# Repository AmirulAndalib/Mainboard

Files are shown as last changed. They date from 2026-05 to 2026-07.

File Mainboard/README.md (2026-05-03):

# Mainboard

## License

Framework Laptop 13 © 2022 by Framework Computer Inc is licensed under CC BY 4.0.
To view a copy of this license, visit http://creativecommons.org/licenses/by/4.0/

# Mechanical

## 2D

2D drawings of the Mainboard with the PCB outline, keepouts, and connector locations.

## OpenSCAD



A basic VESA 75mm mountable 3D printable tray modeled in OpenSCAD, usable as a starting point for more complex cases.

## Printable Case

Case

A fully featured 3D printable case.

# Partial Schematics
Partial schematics are listed for each generation of Framework Laptop 13.  These contain block diagrams, power trees,
and the circuits around each connector.  For full schematics, repair shops can submit a request to our support team
with the serial number of the Mainboard.

Note: Framework Laptop 13 (13th Gen Intel Core) uses the same schematic as (12th Gen Intel Core).

# Framework Laptop Mainboard Pinouts

This is a list of connectors on the Framework Laptop Mainboard and the pinouts for them.
Note that not all signals listed in each pinout are actually connected on any given
version of Mainboard.  These are the overarching definitions of the pinouts with some
considerations for future generations that may or may not utilize the additional signals.

## Webcam Interface

IPEX 20879-030E connector used to interface to the Webcam Module.  Note that the Webcam Module
itself currently only uses a 12 pin connector using pins 19 through 30.  The remaining signals
are not connected.

| Pin | Signal | Type (on Mainboard) | Notes |
|-----|---|---|---|
| 1 | GND | | |
| 2 | CSI_0N | Input | MIPI Lane 0 |
| 3 | CSI_0P | Input | MIPI Lane 0 |
| 4 | GND | | |
| 5 | CSI_1N | Input | MIPI Lane 1 |
| 6 | CSI_1P | Input | MIPI Lane 1 |
| 7 | GND | | |
| 8 | CSI_CLKN | Input | MIPI Clock |
| 9 | CSI_CLKP | Input | MIPI Clock |
| 10  | GND | | |
| 11  | SYNC_CAM | Input/Output | Camera FSIN (Frame Sync) |
| 12  | SCL_CAM  | Input | |
| 13  | SDA_CAM  | Input/Output | |
| 14  | TS_SYNC  | Output | Touchscreen frame sync |
| 15  | TS_RST | Output | Touchscreen reset |
| 16  | TS_INT | Input | Touchscreen interrupt |
| 17  | TS_SDA | Input/Output | Touchscreen data |
| 18  | TS_SCL | Output | Touchscreen data |
| 19  | GND | | |
| 20  | USB_DP | Input/Output | Touchscreen or camera USB 2.0 |
| 21  | USB_DM | Input/Output | Touchscreen or camera USB 2.0 |
| 22  | 3V3 | | |
| 23  | CAM_SW | Input | 3v3 |
| 24  | MIC_CLK  | Output | 1v8 |
| 25  | MIC_DAT  | Input | 1v8 |
| 26  | MIC_SW | Input | 3v3 |
| 27  | INT_ALS  | Input | 3v3 |
| 28  | SCL_ALS  | Output | 3v3 |
| 29  | SDA_ALS  | Input/Output | 3v3 |
| 30  | GND | | |

## Display Interface

IPEX 20879-040E connector used to interface to an eDP display.  Note that there are signals
defined for both USB 2.0 and I2C touchscreens.  There is a PWM interface to control backlight
brightness, but the display currently used on the Framework Laptop converts that to a DC LED
control.  Note that pin 1 is on the left when looking at the receptacle on the Mainboard.

| Pin | Signal | Description |
|-----|---|---|
| 1 | BL_POWER | 12-17V backlight power |
| 2 | BL_POWER | |
| 3 | BL_POWER | |
| 4 | NC | |
| 5 | GND | |
| 6 | AUXP | |
| 7 | AUXN | |
| 8 | GND | |
| 9 | EDP_TXP_0 | |
| 10  | EDP_TXN_0 | |
| 11  | GND | |
| 12  | EDP_TXP_1 | |
| 13  | EDP_TXN_1 | |
| 14  | GND | |
| 15  | EDP_TXP_2 | |
| 16  | EDP_TXN_2 | |
| 17  | GND | |
| 18  | EDP_TXP_3 | |
| 19  | EDP_TXN_3 | |
| 20  | GND | |
| 21  | EDP_HPD | hotplug |
| 22  | BLK_PWM_LCD | Backlight PWM |
| 23  | BLK_OFF_N | Backlight Enable |
| 24  | NC | |
| 25  | NC | |
| 26  | 3V_EDP | 3VS |
| 27  | 3V_EDP | |
| 28  | 3V_EDP | |
| 29  | 3V_TS | 3VS for touchscreen |
| 30  | 3V_TS | |
| 31  | USB_DP | USB |
| 32  | USB_DN | |
| 33  | TS_EN | |
| 34  | TS_RST | |
| 35  | TS_INT_N | |
| 36  | TS_SDA | |
| 37  | TS_SCL | |
| 38  | NC | |
| 39  | GND | |
| 40  | GND | |

## Audio Board Interface

Hefeng AFC42-S15FMA-R3 ZIF connector that goes to the board that has the 3.5mm
audio jack as well as the hall effect lid sensor.  Note that there are likely
other 15 pin 0.5mm pitch ZIF connectors that will work with the FFC we use, but
these would be untested.

| Pin | Signal |
|-----|---|
| 1 | A_GND |
| 2 | HPOUT_L |
| 3 | HPOUT_R |
| 4 | SLEEVE |
| 5 | SLEEVE |
| 6 | SLEEVE |
| 7 | RING |
| 8 | RING |
| 9 | RING |
| 10  | A_GND |
| 11  | JACK_PLUG |
| 12  | 3V3_HALL  |
| 13  | LID_OPEN  |
| 14  | BOARD_ID  |
| 15  | GND |

## Speaker Interface

Hefeng AWA02-S04FIA-HF connector for the Speakers.  Note that there are many other footprint
compatible 4-pin connectors that are likely compatible. This kind of connector is also known
as "JST SH", and has a 1.0 mm pitch. The same connector is used for the Fan.

| Pin | Signal |
|-----|---|
| 1 | SPK_RP |
| 2 | SPK_RN |
| 3 | SPK_LP |
| 4 | SPK_LN |

## Battery Interface

ACES 50458-01001-001 connector for the Battery.

| Pin | Signal | Notes  |
|-----|---|---|
| 1 | BAT+ | 24 AWG |
| 2 | BAT+ | 24 AWG |
| 3 | BAT+ | 24 AWG |
| 4 | CLK_SMB  | SMBus  |
| 5 | DAT_SMB  | SMBus  |
| 6 | BATT_PRS | |
| 7 | SYS_PRES | |
| 8 | GND | 24 AWG |
| 9 | GND | 24 AWG |
| 10  | GND | 24 AWG |

## Input Cover Interface

Amphenol 10156000-051100LF connector for the Input Cover.  This includes signals
for the Touchpad, Keyboard, and Fingerprint Reader. The mating connector for it
is 10156001-051100LF.

Caution: this pinout is Framework schematic-specific, using a symbol with odd-even numbering.
It doesn't translate directly to the Amphenol connector footprint numbering - which is
counterclockwise. Amphenol connector numbering is shown in the "Conn" column.

| Pin | Conn | Signal | Notes |
|-----|---|---|---|
| 1 | 1 | GND | |
| 2 | 50 | KSI0 | Keyboard scanning input 0 |
| 3 | 2 | KSI1 | Keyboard scanning input 1 |
| 4 | 49 | KSI2 | Keyboard scanning input 2 |
| 5 | 3 | KSI3 | Keyboard scanning input 3 |
| 6 | 48 | KSI4 | Keyboard scanning input 4 |
| 7 | 4 | KSI5 | Keyboard scanning input 5 |
| 8 | 47 | KSI6 | Keyboard scanning input 6 |
| 9 | 5 | KSI7 | Keyboard scanning input 7 |
| 10  | 46 | KSO0 | Keyboard scanning output 0 |
| 11  | 6 | KSO1 | Keyboard scanning output 1 |
| 12  | 45 | KSO2 | Keyboard scanning output 2 |
| 13  | 7 | KSO3 | Keyboard scanning output 3 |
| 14  | 44 | KSO4 | Keyboard scanning output 4 |
| 15  | 8 | KSO5 | Keyboard scanning output 5 |
| 16  | 43 | KSO6 | Keyboard scanning output 6 |
| 17  | 9 | KSO7 | Keyboard scanning output 7 |
| 18  | 42 | KSO8 | Keyboard scanning output 8 |
| 19  | 10 | KSO9 | Keyboard scanning output 9 |
| 20  | 41 | KSO10 | Keyboard scanning output 10  |
| 21  | 11 | KSO11 | Keyboard scanning output 11  |
| 22  | 40 | KSO12 | Keyboard scanning output 12  |
| 23  | 12 | KSO13 | Keyboard scanning output 13  |
| 24  | 39 | KSO14 | Keyboard scanning output 14  |
| 25  | 13 | KSO15 | Keyboard scanning output 15  |
| 26  | 38 | GND | |
| 27  | 14 | CAPS_P | +5VS through 1.33k resistor  |
| 28  | 37 | CAPS_N | Low-side control by the EC |
| 29  | 15 | GND | |
| 30  | 36 | KBL_P | High-side 5V PWM by the EC |
| 31  | 16 | GND | |
| 32  | 35 | KBL_P | Same as 30 - see [1] |
| 33  | 17 | GND | |
| 34  | 34 | TP_SCL | Touchpad I2C SCL |
| 35  | 18 | TP_INT | Touchpad interrupt GPIO |
| 36  | 33 | TP_SDA | Touchpad I2C SDA |
| 37  | 19 | TP_BOARD_ID | |
| 38  | 32 | 5VS | 5V, touchpad - see [2] |
| 39  | 20 | 5VALW | 5V, fingerprint, see [3] |
| 40  | 31 | USB_DM | Fingerprint sensor USB |
| 41  | 21 | GND | |
| 42  | 30 | USB_DP | Fingerprint sensor USB |
| 43  | 22 | FPR_CTRL | See [4] |
| 44  | 29 | SWITCH | Power button pin |
| 45  | 23 | FPR_LED_R | Low-side control by the EC |
| 46  | 28 | FPR_LED_W | Low-side control by the EC |
| 47  | 24 | FPR_LED_G | Low-side control by the EC |
| 48  | 27 | FPR_LED_COM | 5V, fingerprint LED, see [3] |
| 49  | 25 | GND | |
| 50  | 26 | NC | |

- [1] The connector has two KBL_P pins - in order to increase current capacity. They're created from +5VS rail.
- [2] Connected to the +5VS (switched) rail through a 0 ohm resistor
- [3] Connected to the +5VALW (always-on) rail through a 0 ohm resistor
- [4] FPR_CTRL is used to filter out power button presses while the fingerprint sensor is scanning

## Fan Interface

Hefeng AWA02-S04FIA-HF connector for the Fan.  Note that there are many other footprint
compatible 4-pin connectors that are likely compatible. This kind of connector is also known
as "JST SH", and has a 1.0 mm pitch. The same connector is used for the Speakers.

| Pin | Signal |
|-----|---|
| 1 | 5V |
| 2 | FAN_SPEED |
| 3 | FAN_PWM |
| 4 | GND |

## RTC Battery Interface

NOTE: The mainboard will charge this battery, so a rechargable ML1220 battery MUST be used.
For example, CR2032 MUST NOT be used, it cannot be charged and will likely be damaged.

RTC battery is used for storing persistent but resettable information.
This includes the time and DRAM training. Disconnection will result in deletion of that information.
If no battery is connected, DRAM training needs to happen on every boot, slowing down the boot process significantly.

### Onboard RTC Battery

Framework 13 Intel Core 11th through 13th Generation use an onboard coin cell battery as RTC.

We use the Lotes LOTES_AAA-BAT-046-K01 connector.

### RTC Battery Cable Connector

On AMD Platforms and starting with Framework 13 Intel Core Ultra Series 1, no RTC battery is included anymore.
Settings are kept alive by the normal system battery. The only case where an
RTC battery is recommended, is when the system is used in standalone mode (without a battery).

Cvilux CVILU_CI4402M1HRC-NH connector for the RTC Battery.

| Pin | Signal | Location |
|-----|---|---|
| 1 | +RTCBATT  | Left |
| 2 | GND | Right |

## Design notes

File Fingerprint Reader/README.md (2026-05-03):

## Fingerprint Reader

## License

Framework Laptop 13 © 2022 by Framework Computer Inc is licensed under CC BY 4.0.
To view a copy of this license, visit http://creativecommons.org/licenses/by/4.0/

## Pinout

The Fingerprint Reader resides on the Input Cover and connects through the Touchpad.
All of its signals are directly passed to the Input Cover Interface described in the
Mainboard documentation. The connector used is Kyocera 046809610110846+.

| Pin | Signal | Notes |
|-----|---|---|
| 1 | VBUS | 5V |
| 2 | USB_DP | USB data |
| 3 | USB_DM | USB data |
| 4 | GND | |
| 5 | FPR_CTRL | Output (mask switch events)  |
| 6 | SWITCH | Open collector output |
| 7 | FPR_LED_W | |
| 8 | FPR_LED_G | |
| 9 | FPR_LED_R | |
| 10  | FPR_LED_COM | 5V |

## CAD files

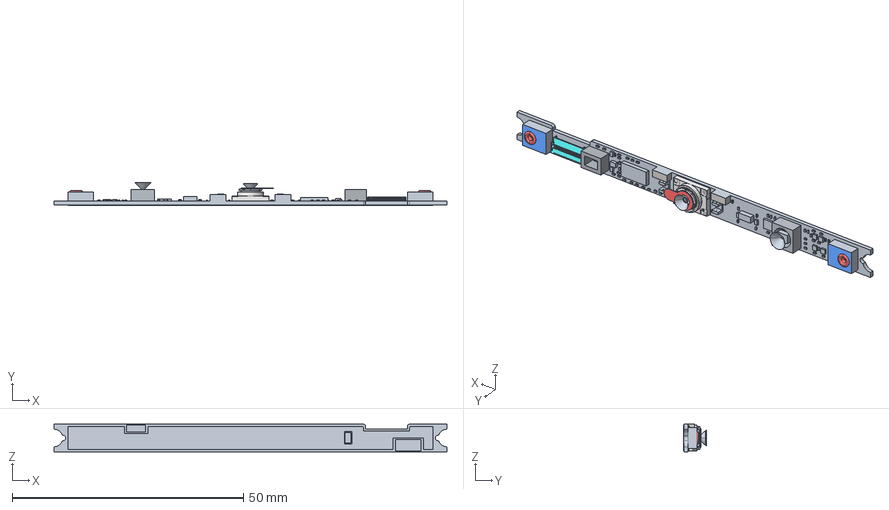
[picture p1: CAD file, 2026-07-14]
Webcam/FW_13_camera_module.stp
85.0 x 4.93 x 6.00 mm

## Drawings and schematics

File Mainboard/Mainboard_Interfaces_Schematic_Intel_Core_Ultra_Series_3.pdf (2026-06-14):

# Block Diagram

## CAMM2

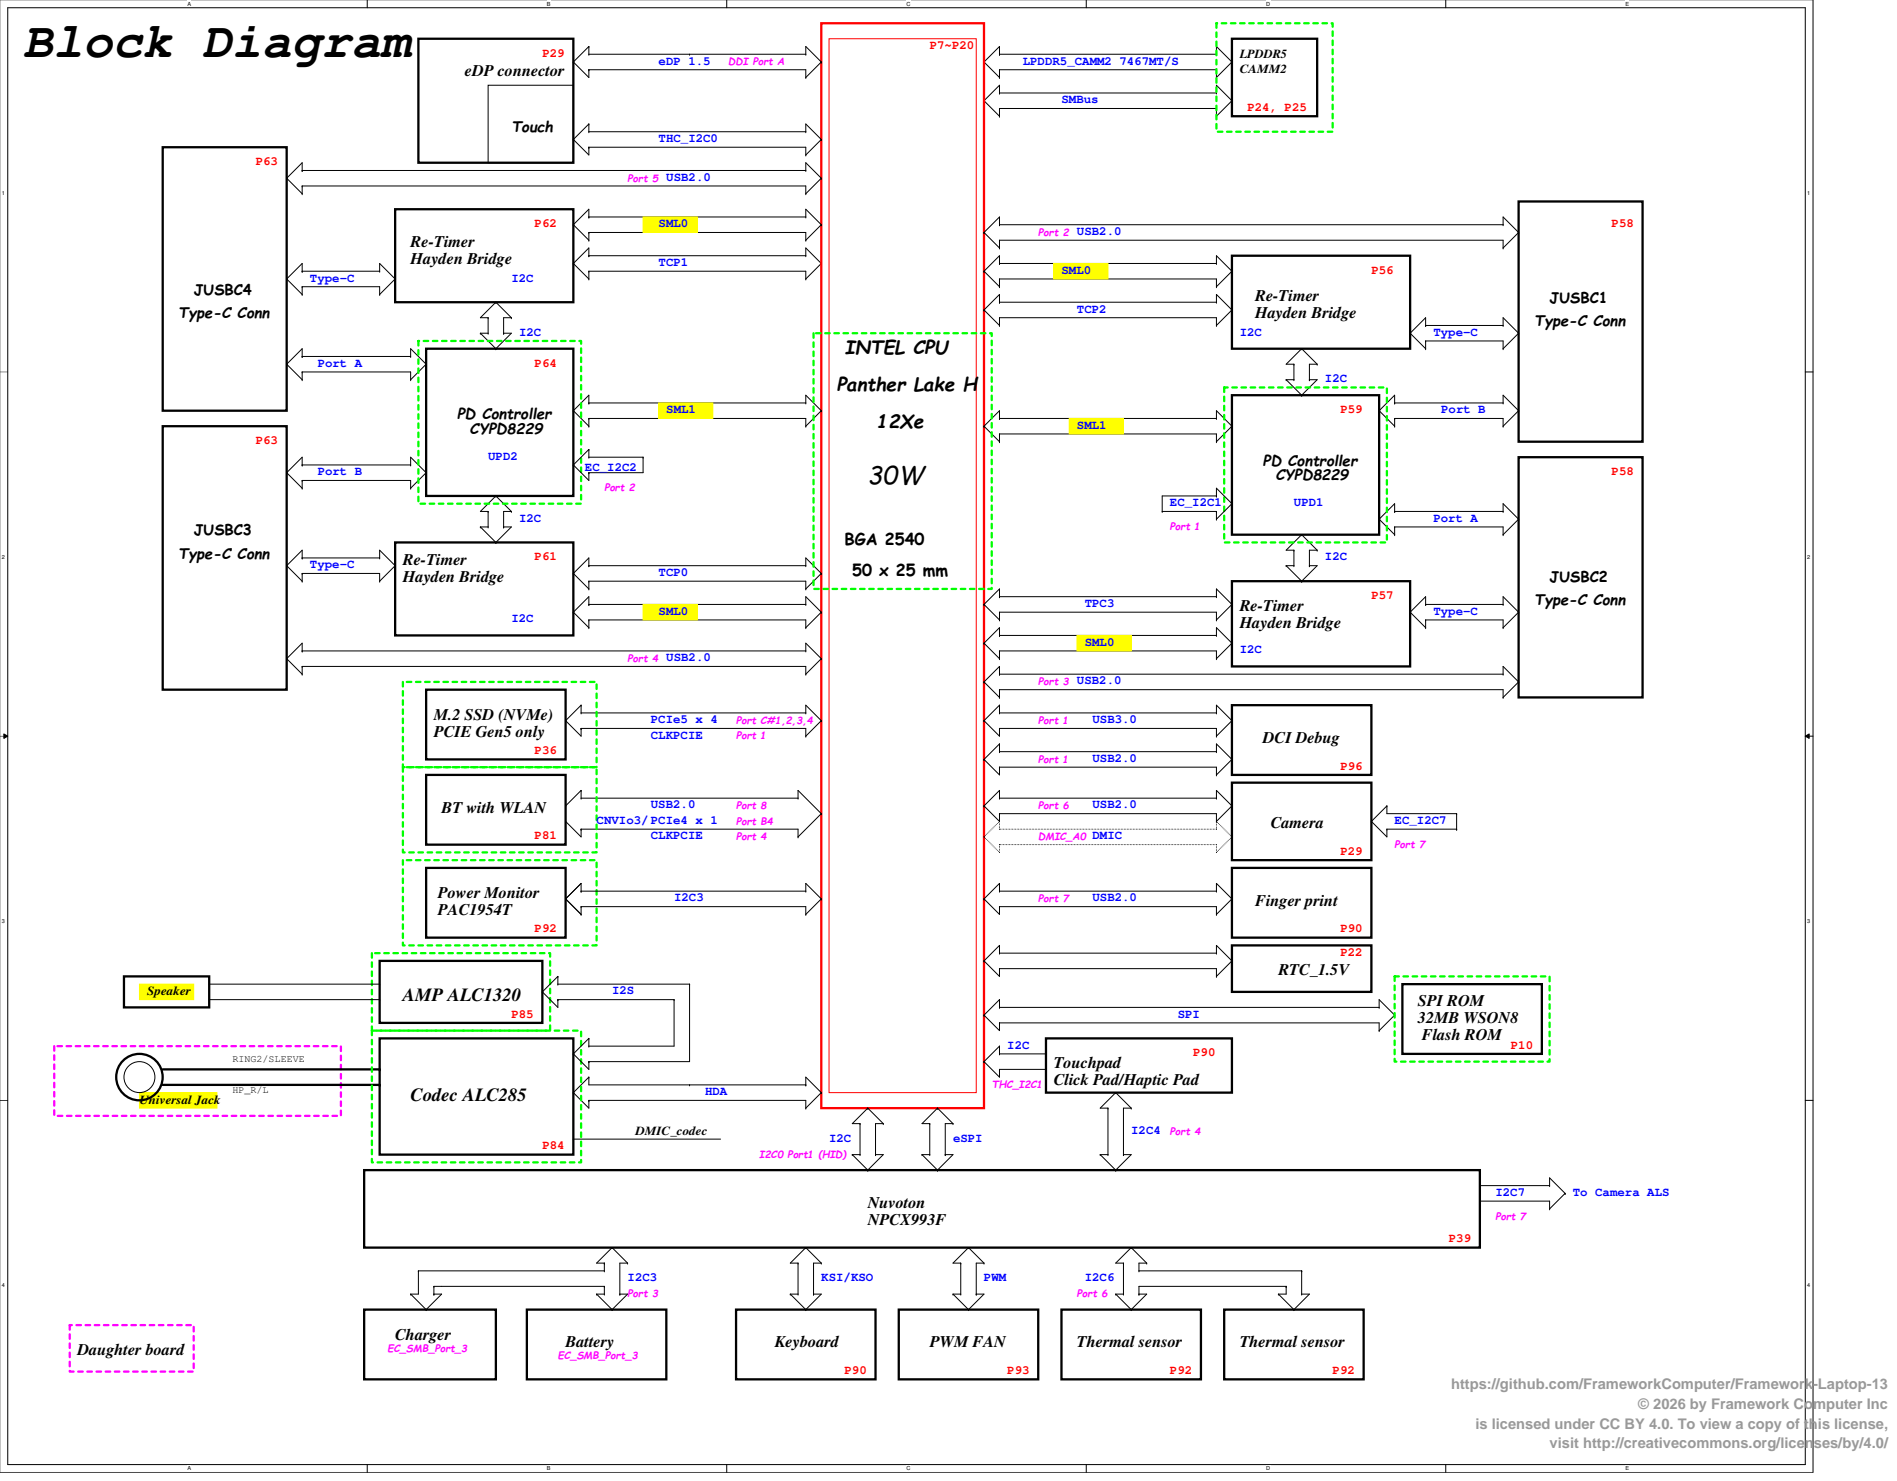
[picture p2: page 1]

Touchpad
Click Pad/Haptic Pad

https://github.com/FrameworkComputer/Framework-Laptop-13

© 2026 by Framework Computer Inc

is licensed under CC BY 4.0. To view a copy of this license,

visit http://creativecommons.org/licenses/by/4.0/

+18.2VB

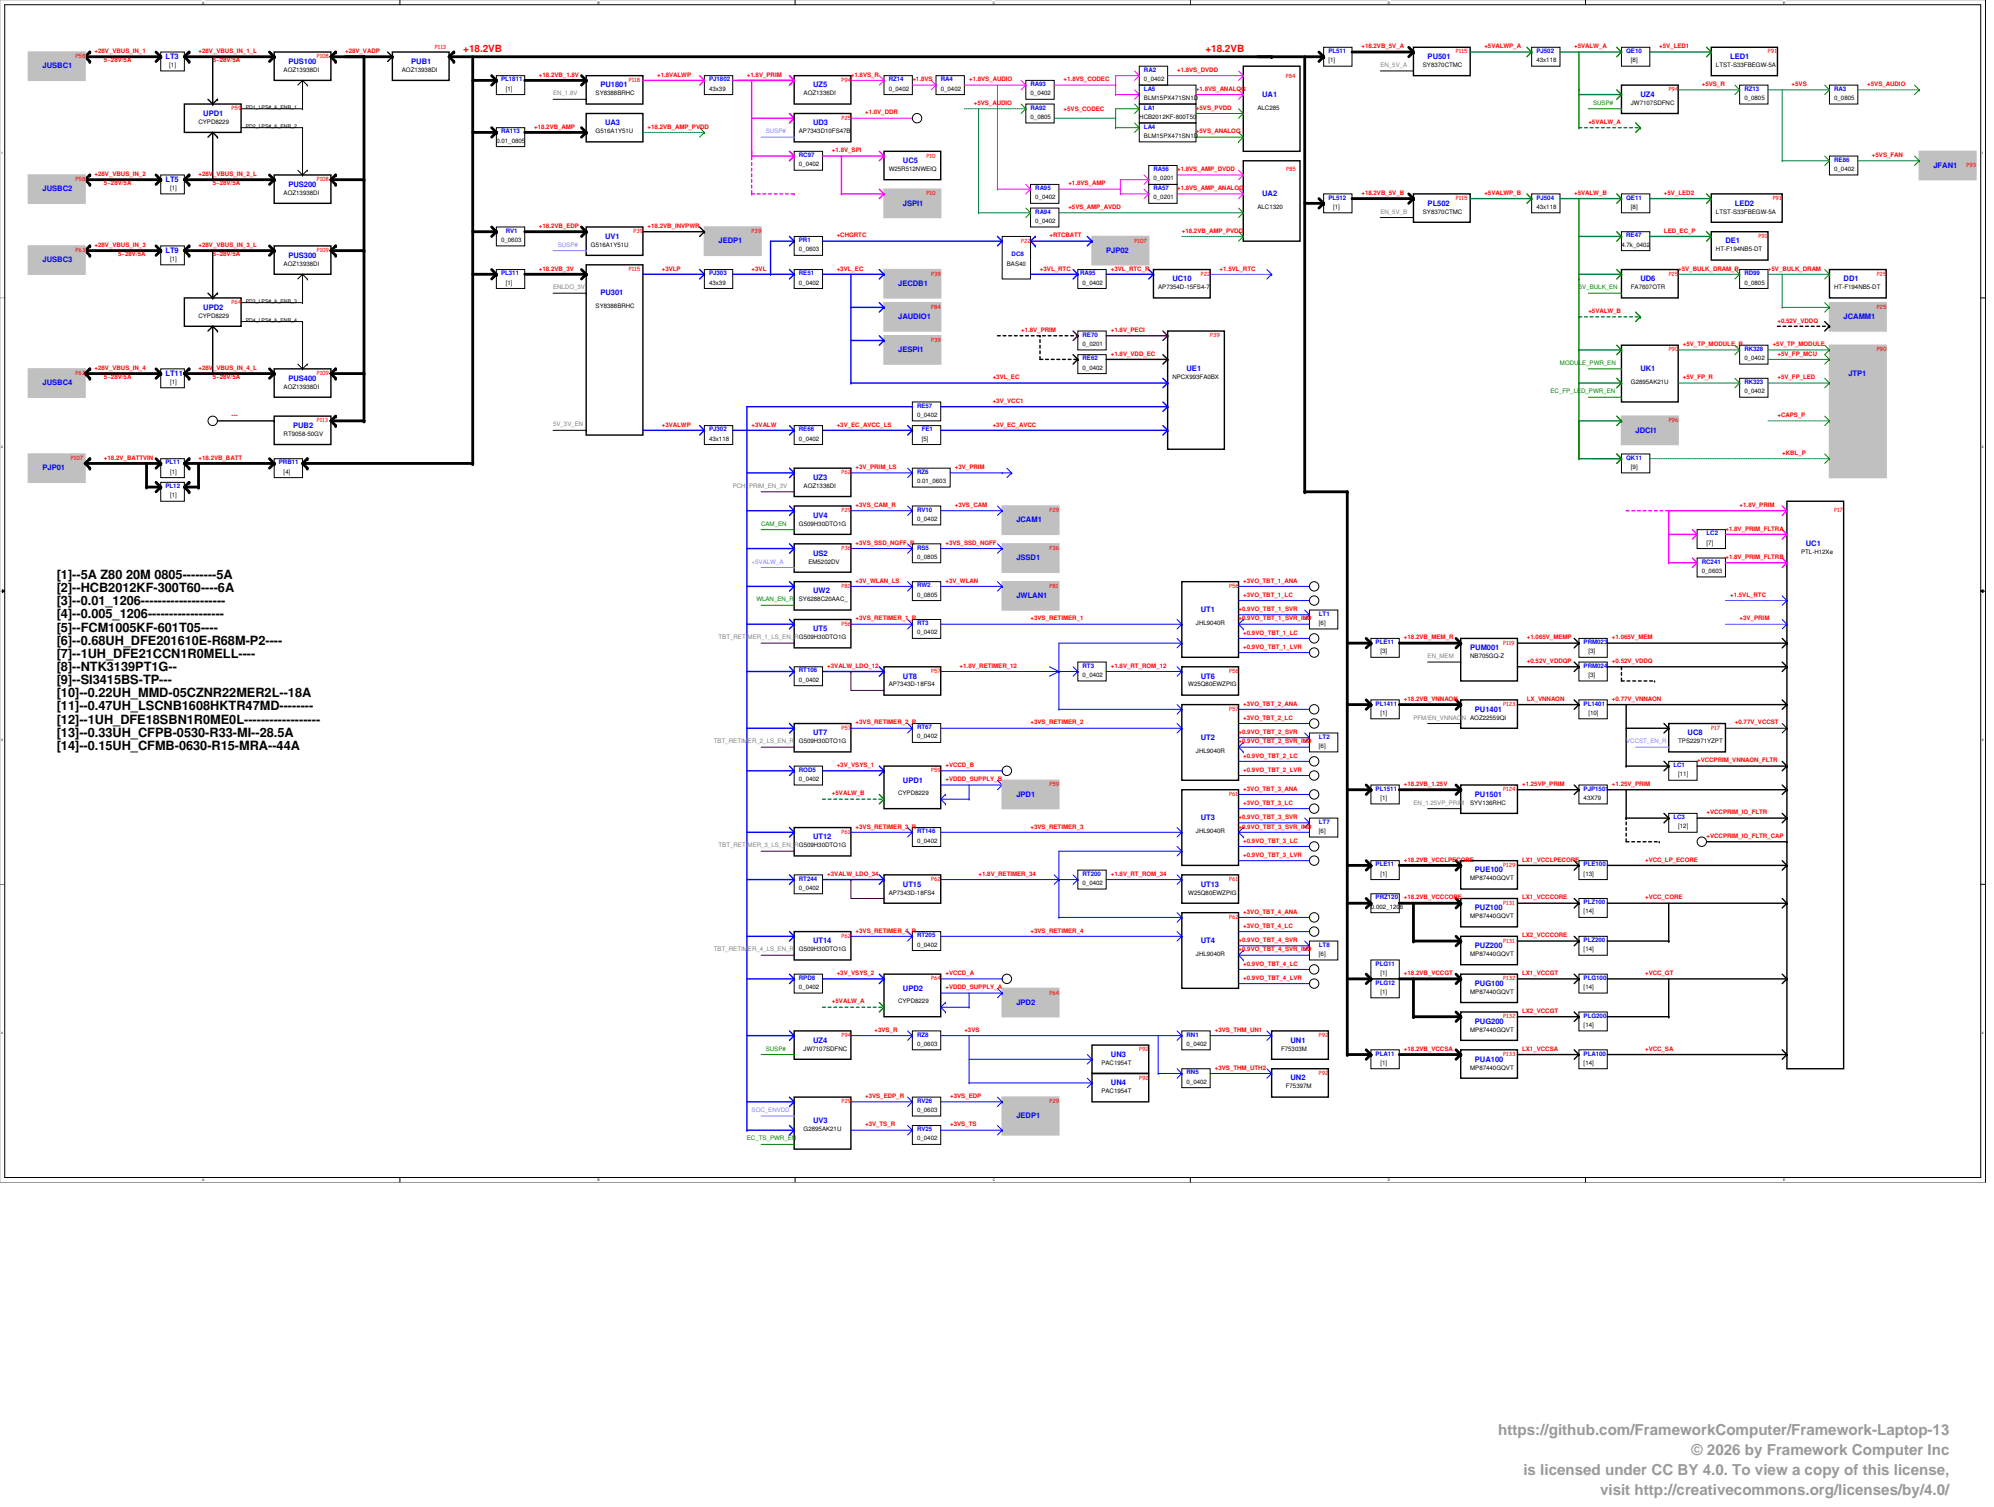
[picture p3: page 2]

# eDP

# eDP Logic and Touch Screen power

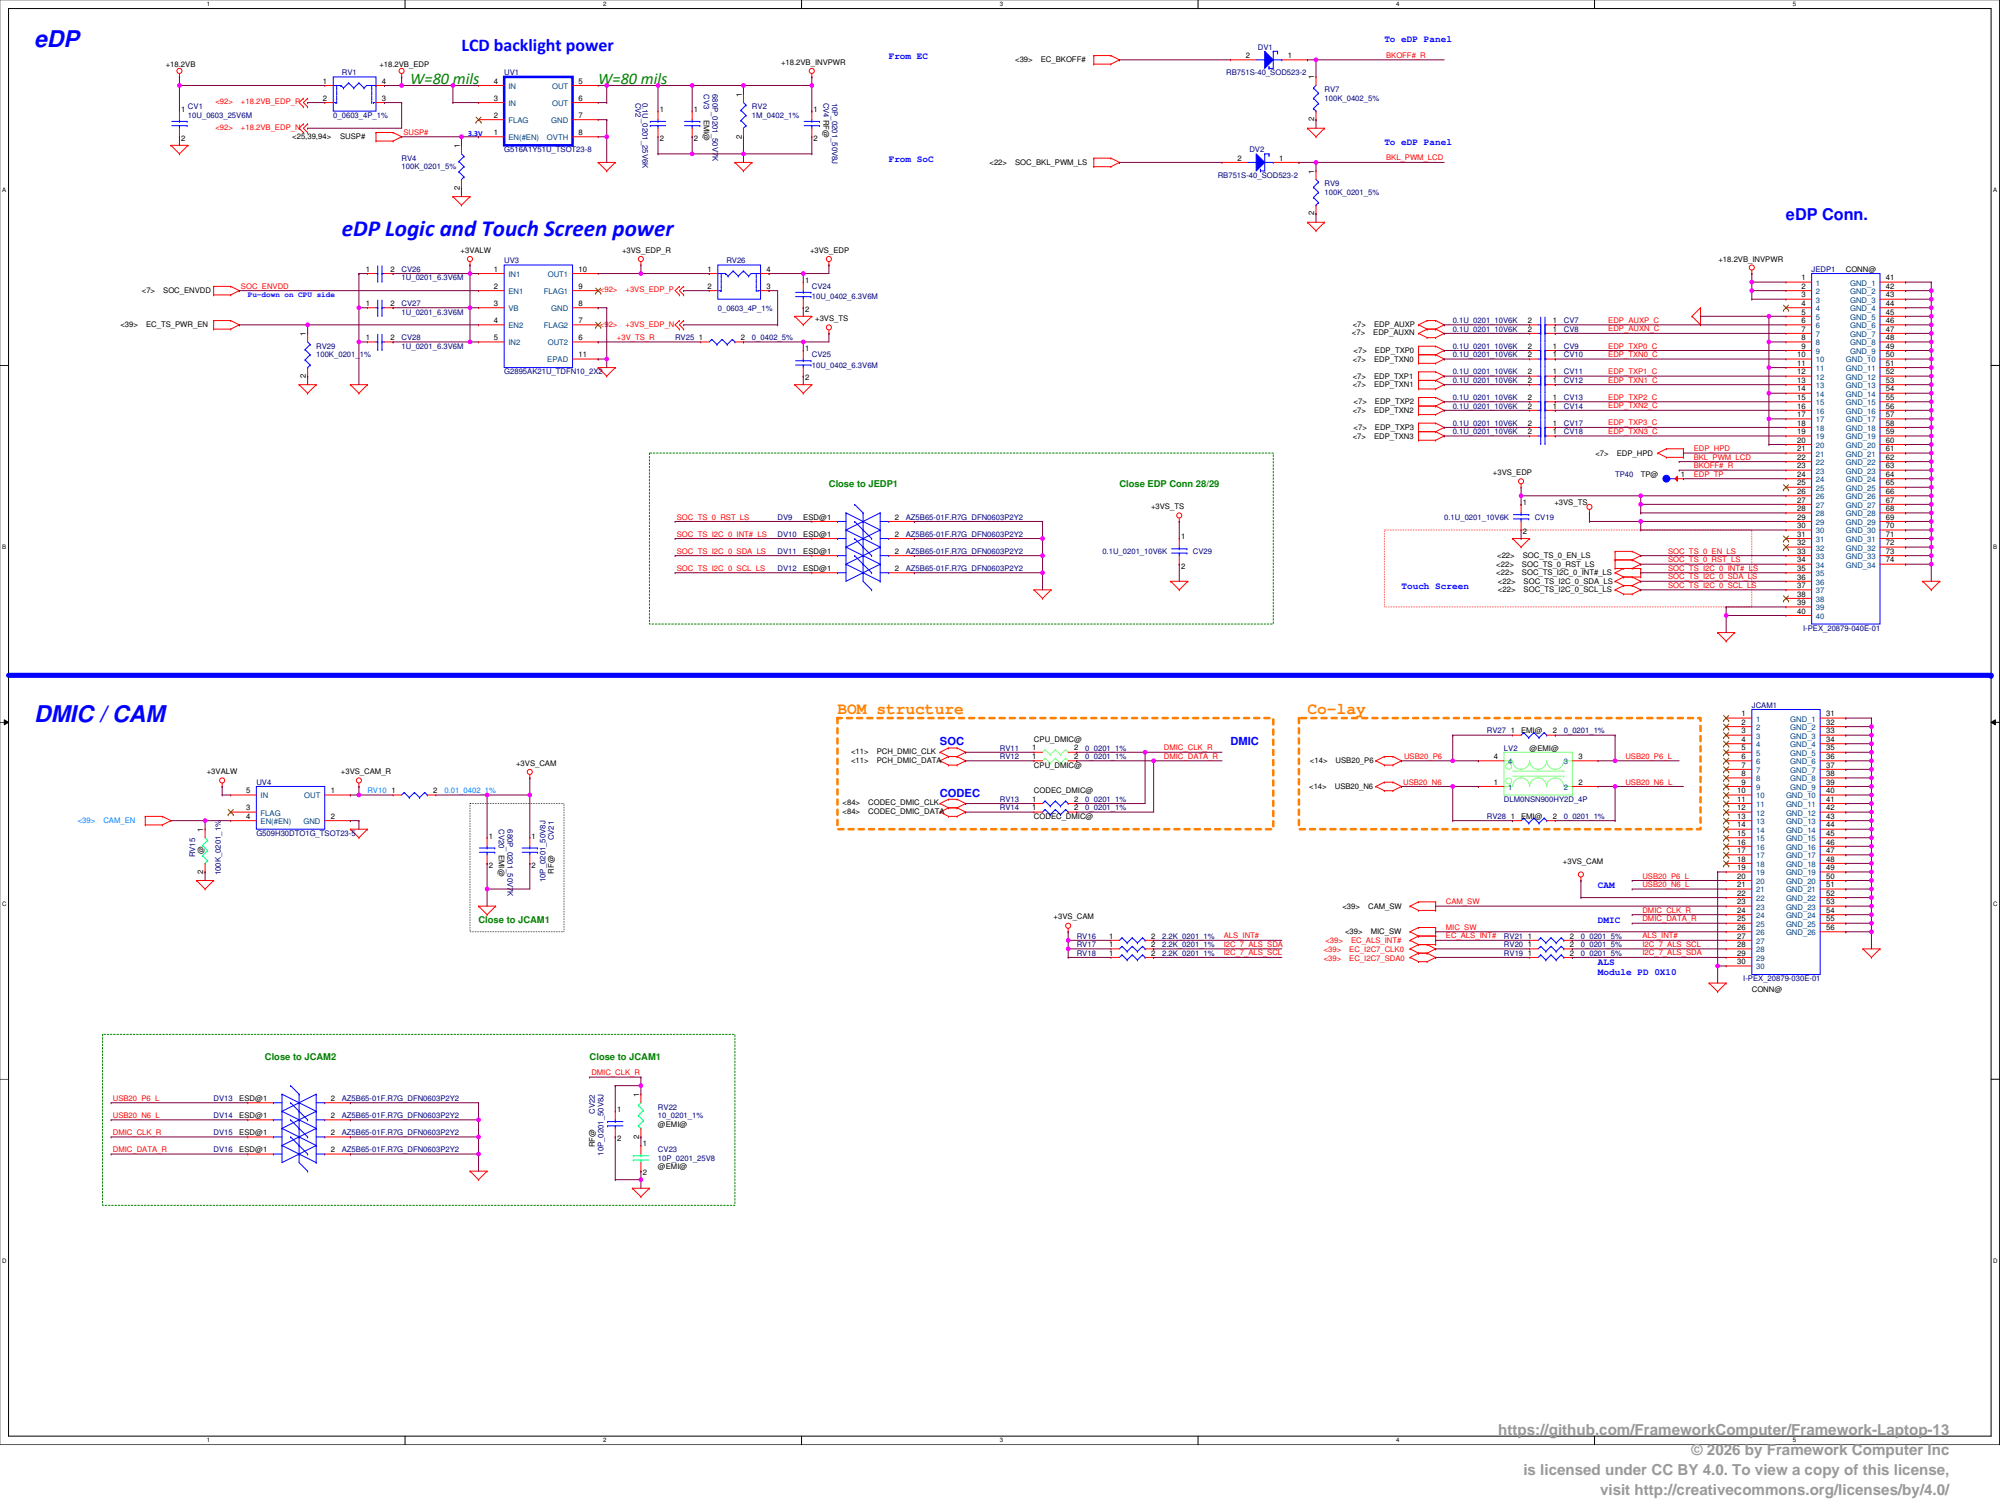
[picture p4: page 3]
From SoC; From EC; DMIC / CAM; CAM; ALS Module PD 0X10; DMIC; W=80 mils; SOC; CODEC; BOM structure; Close to JEDP1; eDP Conn.; Touch Screen; Co-lay; Close to JCAM1; Close to JCAM2; <22> SOC_BKL_PWM_LS; <39> MIC_SW; <39> CAM_SW; <39> CAM_EN; SUSP#; <39> EC_BKOFF#; <7> SOC_ENVDD; <39> EC_TS_PWR_EN; <39> EC_ALS_INT#; <11> PCH_DMIC_CLK <11> PCH_DMIC_DATA; <84> CODEC_DMIC_CLK <84> CODEC_DMIC_DATA; <14> USB20_P6; <14> USB20_N6; <7> EDP_AUXP <7> EDP_AUXN; <7> EDP_TXP0 <7> EDP_TXN0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

LCD backlight power

To eDP Panel

SOC_ENVDD
Pu-down on CPU side

Close EDP Conn 28/29

# NGFF SSD (KEY M)

# PCIE Gen5

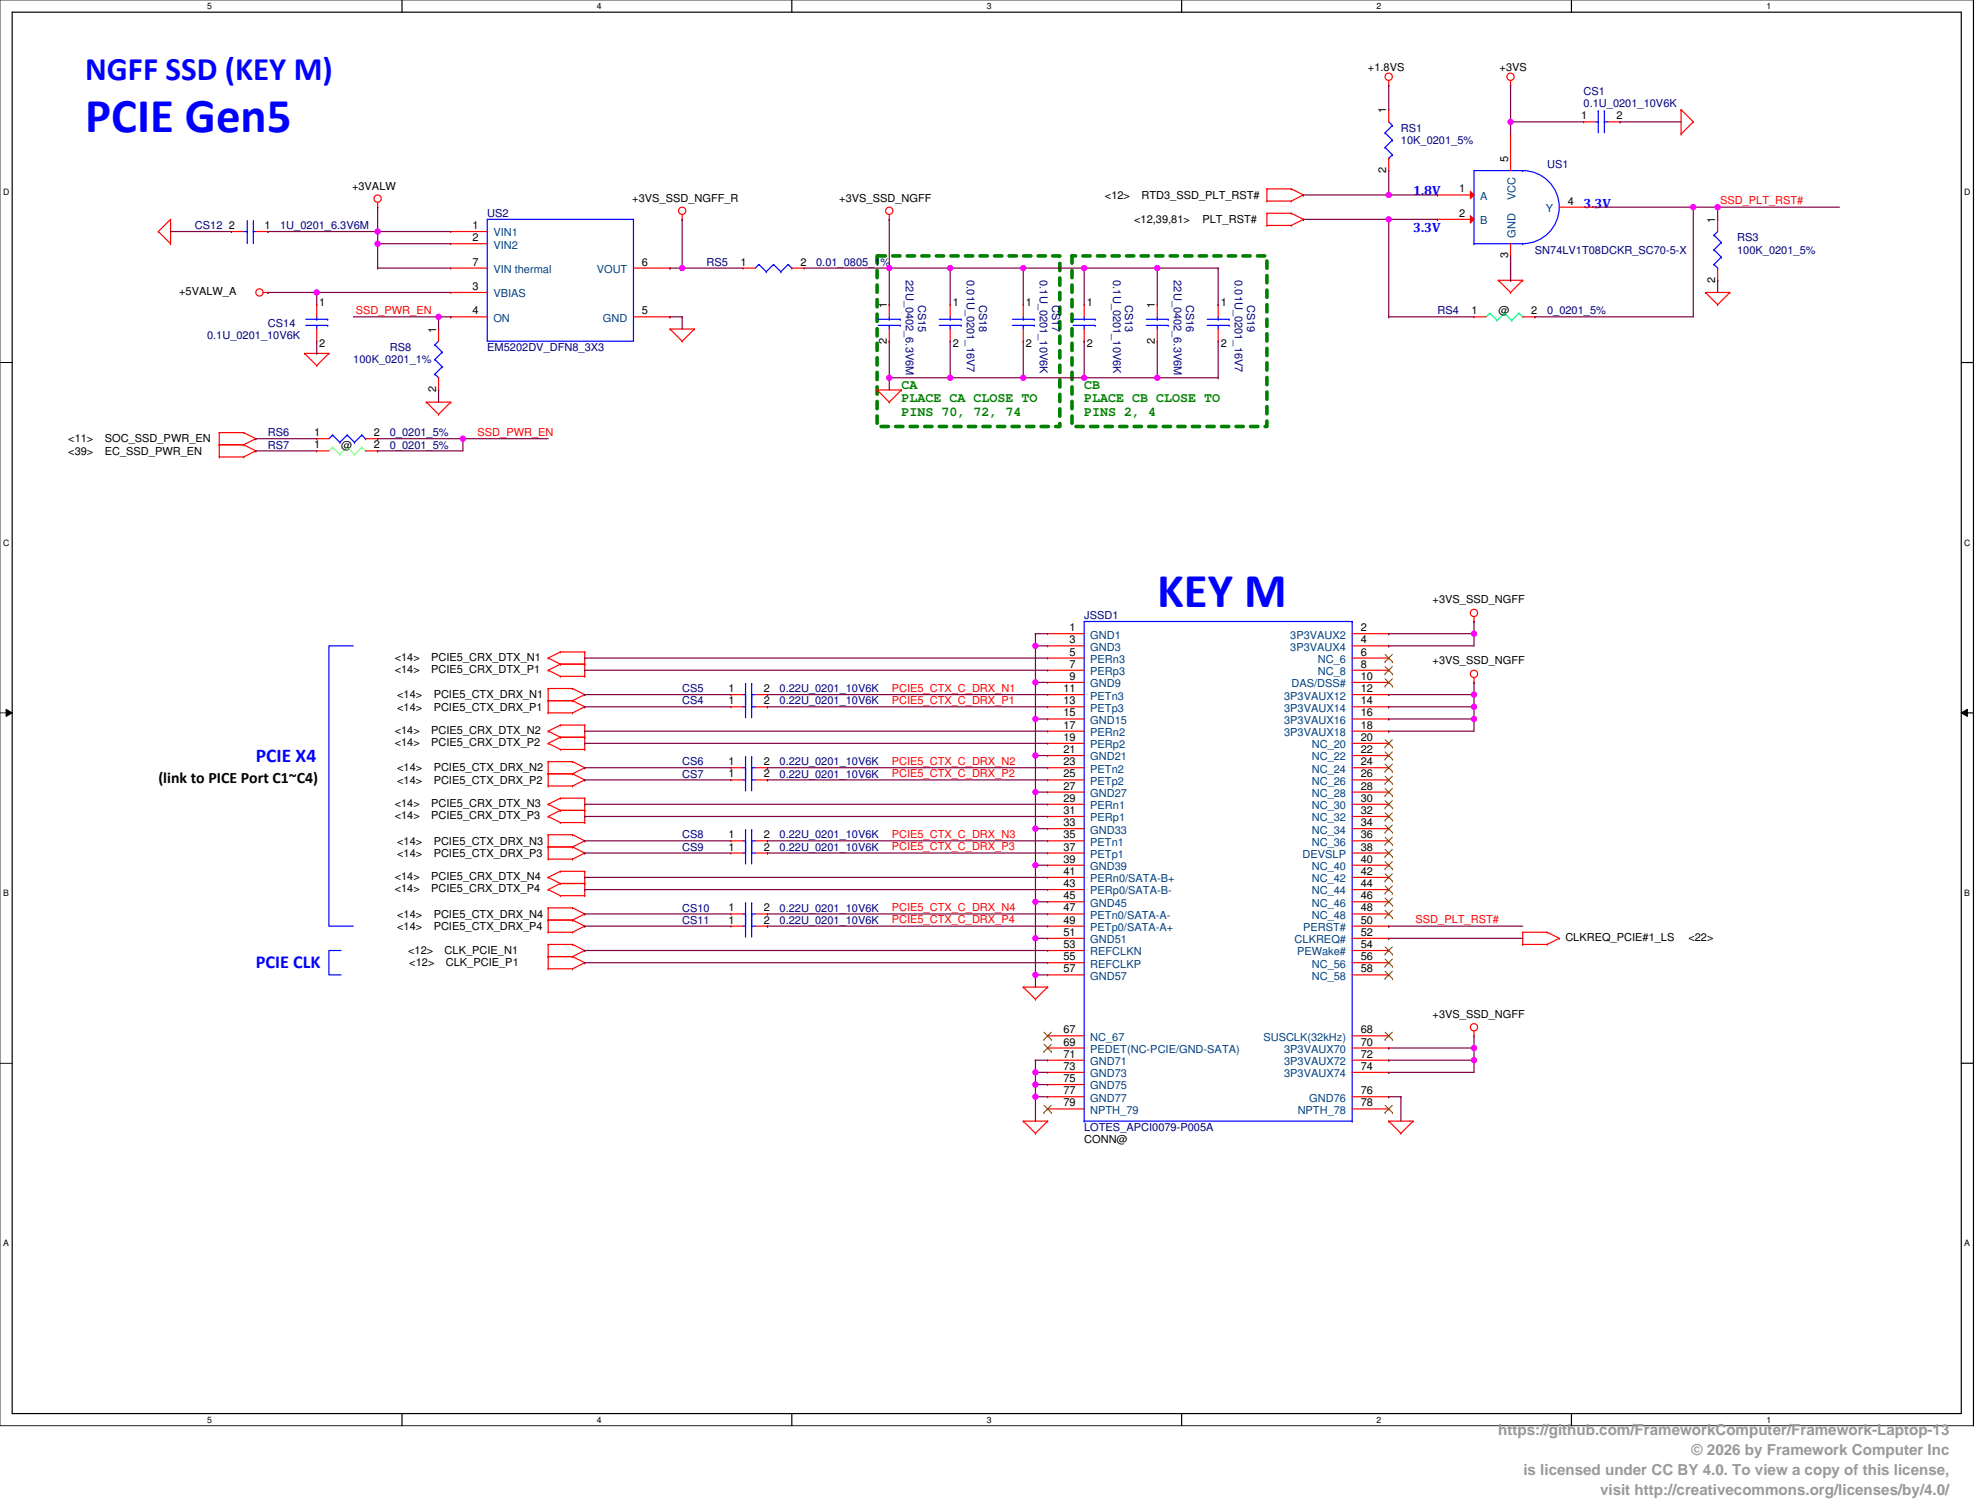
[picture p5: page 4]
PCIE X4; KEY M; PCIE CLK; CLKREQ_PCIE#1_LS; <12> CLK_PCIE_P1; <12> CLK_PCIE_N1; <12> RTD3_SSD_PLT_RST#; <12,39,81> PLT_RST#; <14> PCIE5_CRX_DTX_N3 <14> PCIE5_CRX_DTX_P3; <14> PCIE5_CTX_DRX_N3 <14> PCIE5_CTX_DRX_P3; <14> PCIE5_CRX_DTX_N2 <14> PCIE5_CRX_DTX_P2; <14> PCIE5_CTX_DRX_N2 <14> PCIE5_CTX_DRX_P2; <14> PCIE5_CRX_DTX_N4 <14> PCIE5_CRX_DTX_P4; <14> PCIE5_CTX_DRX_N4 <14> PCIE5_CTX_DRX_P4; <14> PCIE5_CRX_DTX_N1 <14> PCIE5_CRX_DTX_P1; <14> PCIE5_CTX_DRX_N1 <14> PCIE5_CTX_DRX_P1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

PLACE CA CLOSE TO
PINS 70, 72, 74

PLACE CB CLOSE TO
PINS 2, 4

(link to PICE Port C1~C4)

# Imax : 2.0 A

# Main Func = NGFF WLAN / BT (Key E)

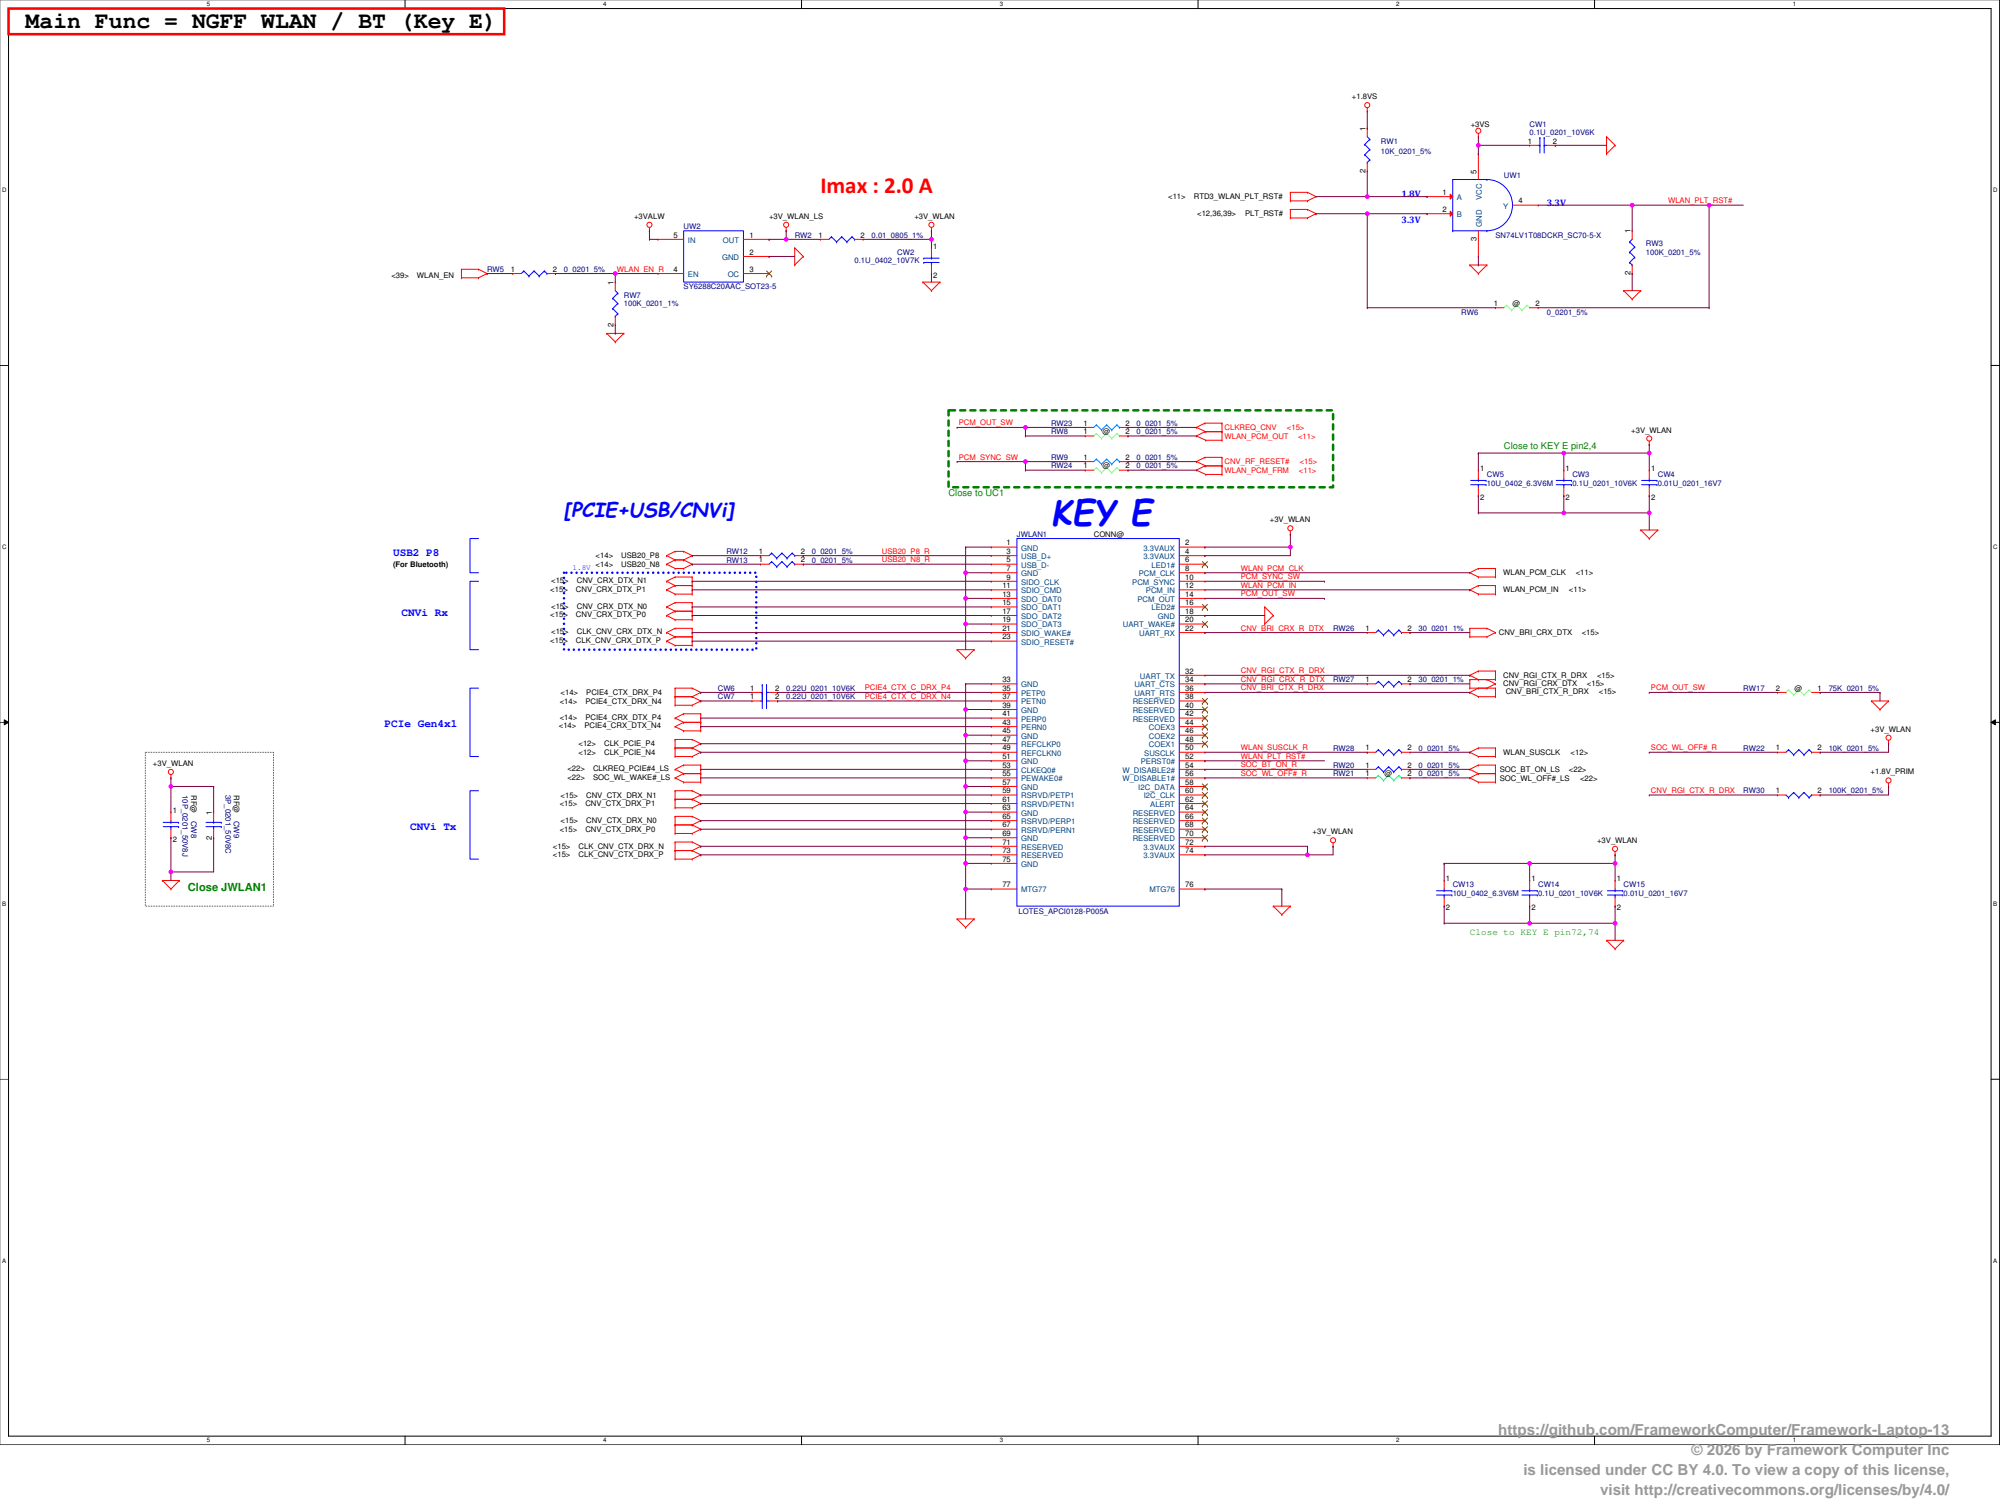
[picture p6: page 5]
CNVi Rx; USB2 P8; (For Bluetooth); CNVi Tx; [PCIE+USB/CNVi]; KEY E; Close JWLAN1; PCIe Gen4x1; Close to UC1; SOC_BT_ON_LS; WLAN_SUSCLK; <14> USB20_P8 <14> USB20_N8; <15> CNV_CRX_DTX_N1 <15> CNV_CRX_DTX_P1; <15> CNV_CRX_DTX_N0 <15> CNV_CRX_DTX_P0; <14> PCIE4_CTX_DRX_P4 <14> PCIE4_CTX_DRX_N4; <14> PCIE4_CRX_DTX_P4 <14> PCIE4_CRX_DTX_N4; <12> CLK_PCIE_P4 <12> CLK_PCIE_N4; <22> CLKREQ_PCIE#4_LS <22> SOC_WL_WAKE#_LS; <15> CNV_CTX_DRX_N1 <15> CNV_CTX_DRX_P1; <15> CNV_CTX_DRX_N0 <15> CNV_CTX_DRX_P0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

Close to KEY E pin2,4

Close to KEY E pin72,74

# Main Func = TP_FP PWR

# Main Func = Keyboard

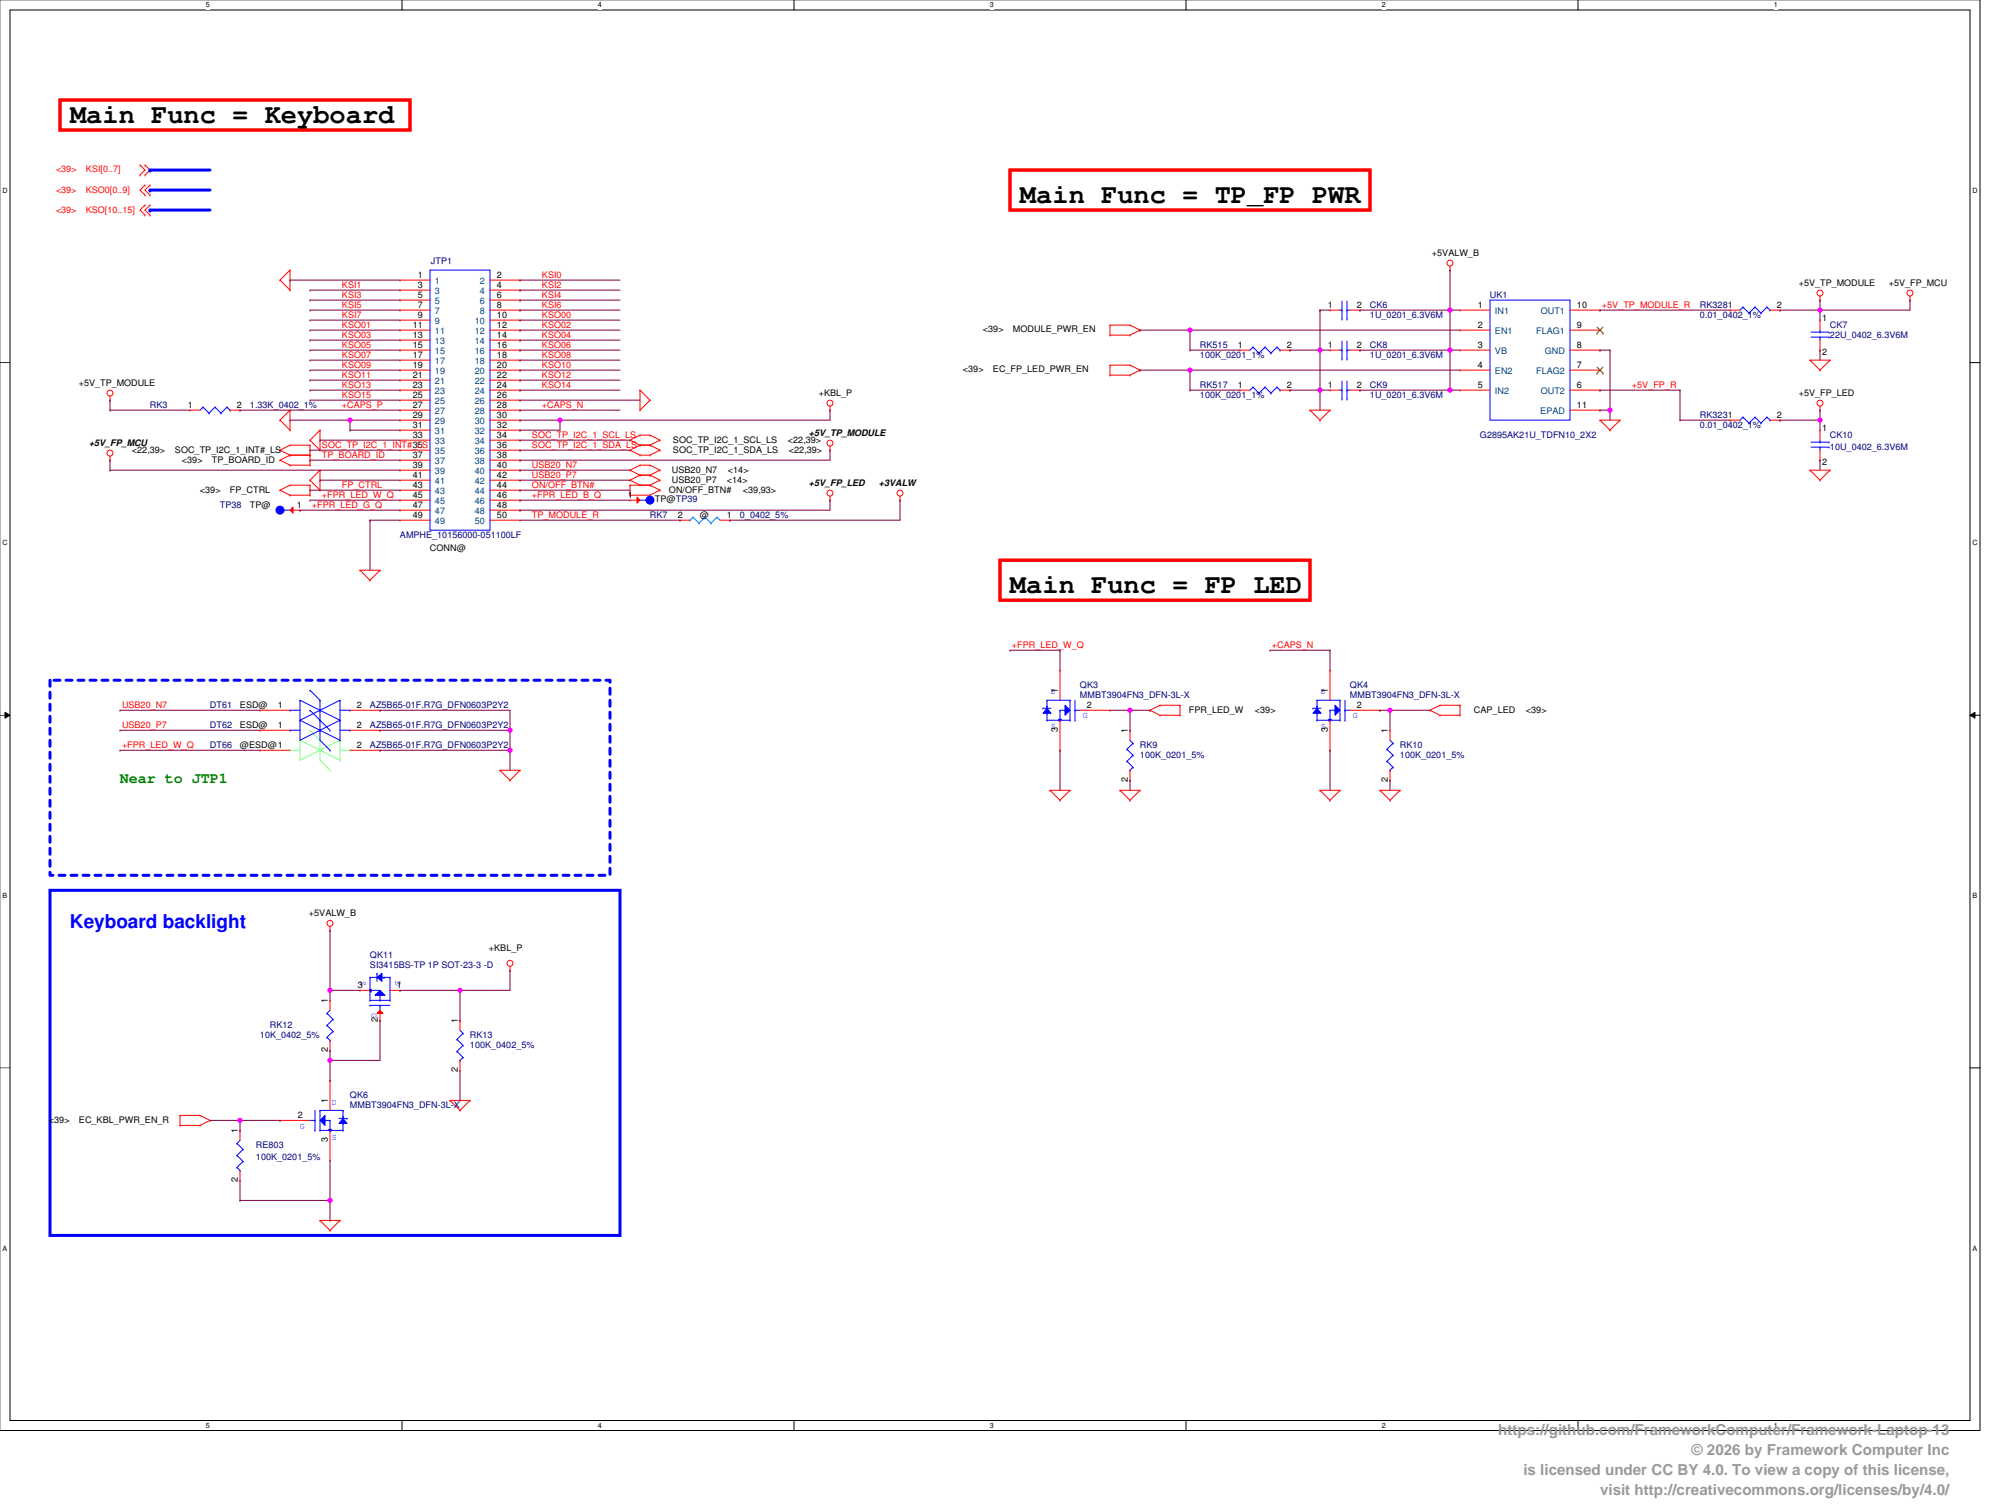
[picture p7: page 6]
Keyboard backlight; Near to JTP1; <39> FP_CTRL; <39> TP_BOARD_ID; <22,39> SOC_TP_I2C_1_INT#_LS; ON/OFF_BTN#; USB20_P7 <14>; USB20_N7; SOC_TP_I2C_1_SDA_LS; SOC_TP_I2C_1_SCL_LS; <39> EC_KBL_PWR_EN_R; <39> MODULE_PWR_EN; <39> EC_FP_LED_PWR_EN; FPR_LED_W; CAP_LED; +5V_TP_MODULE; +5VALW_B; +KBL_P; +5V_FP_LED; +5V_FP_MCU; +3VALW; <39> KSI[0..7]; <39> KSO0[0..9]; <39> KSO[10..15]; AZ5B65-01F.R7G_DFN0603P2Y2 @ESD@1; AZ5B65-01F.R7G_DFN0603P2Y2 ESD@ 1; JTP1; AMPHE_10156000-051100LF CONN@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

Main Func = FP LED

# Main Func = LED

Left TBT LED | Right TBT LED

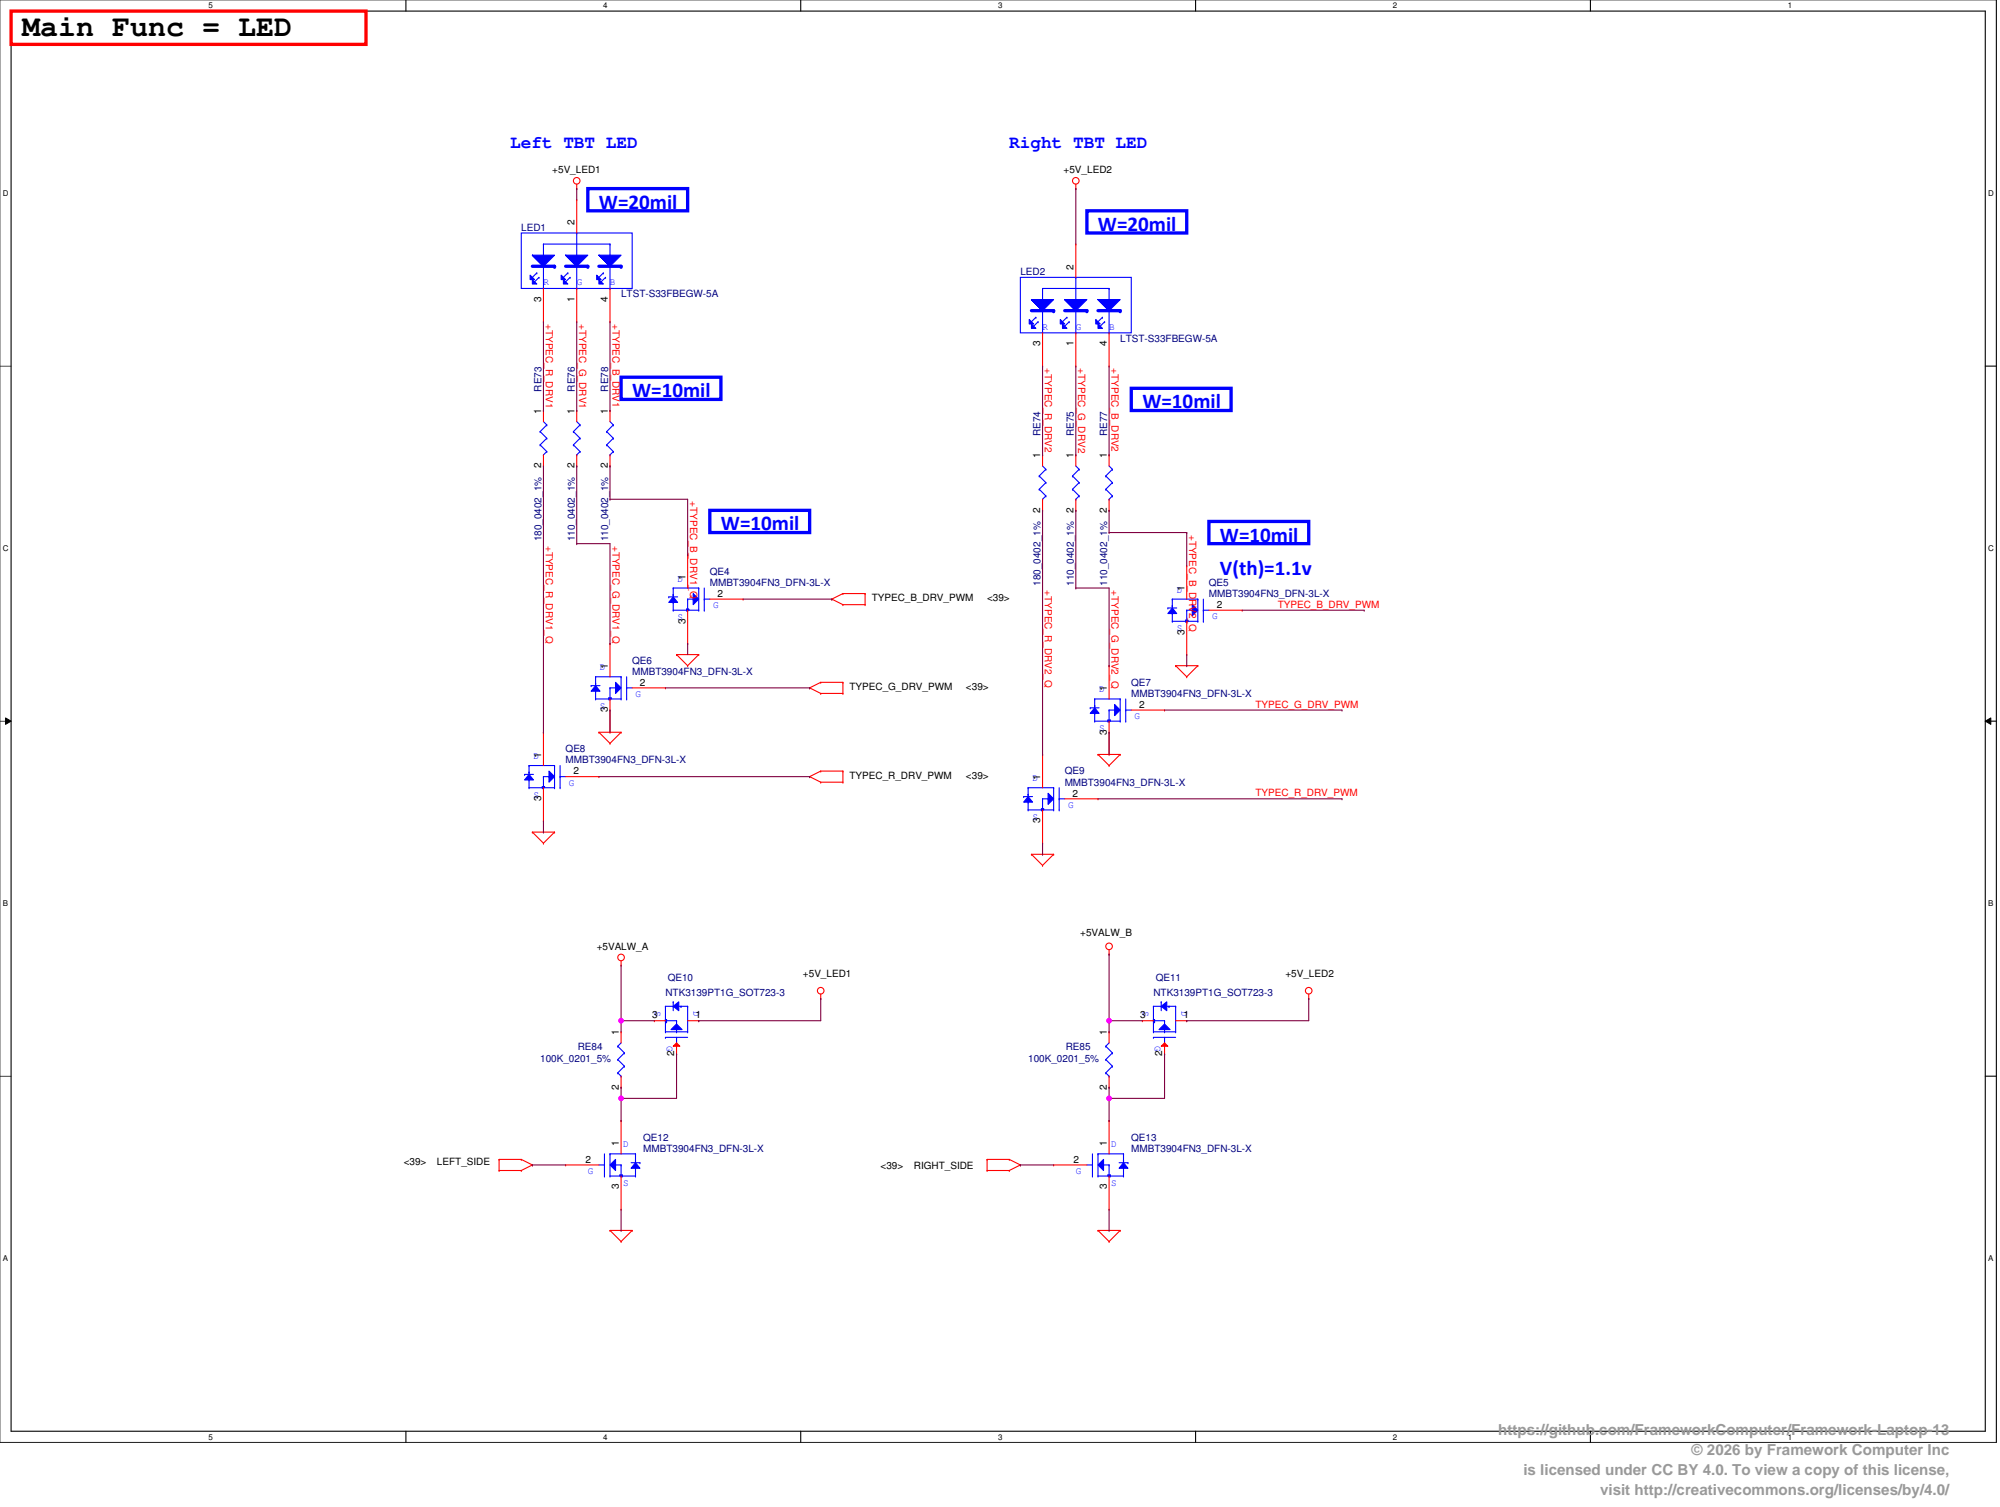
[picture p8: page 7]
W=10mil; W=20mil; TYPEC_G_DRV_PWM; TYPEC_R_DRV_PWM; <39> LEFT_SIDE; <39> RIGHT_SIDE; TYPEC_B_DRV_PWM; +5V_LED1; +5V_LED2; +5VALW_A; +5VALW_B; QE9 MMBT3904FN3_DFN-3L-X 2; LED1; LTST-S33FBEGW-5A; QE7 MMBT3904FN3_DFN-3L-X 2; QE13 MMBT3904FN3_DFN-3L-X; LED2; QE8 MMBT3904FN3_DFN-3L-X 2; NTK3139PT1G_SOT723-3; QE5 MMBT3904FN3_DFN-3L-X 2; QE12 MMBT3904FN3_DFN-3L-X; QE4 MMBT3904FN3_DFN-3L-X 2; QE6 MMBT3904FN3_DFN-3L-X 2; +TYPEC_R_DRV1; +TYPEC_G_DRV1; +TYPEC_B_DRV1; +TYPEC_R_DRV2; +TYPEC_G_DRV2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

# Main Func = Sensor_TPM_LED

## F75303 (0X4D)

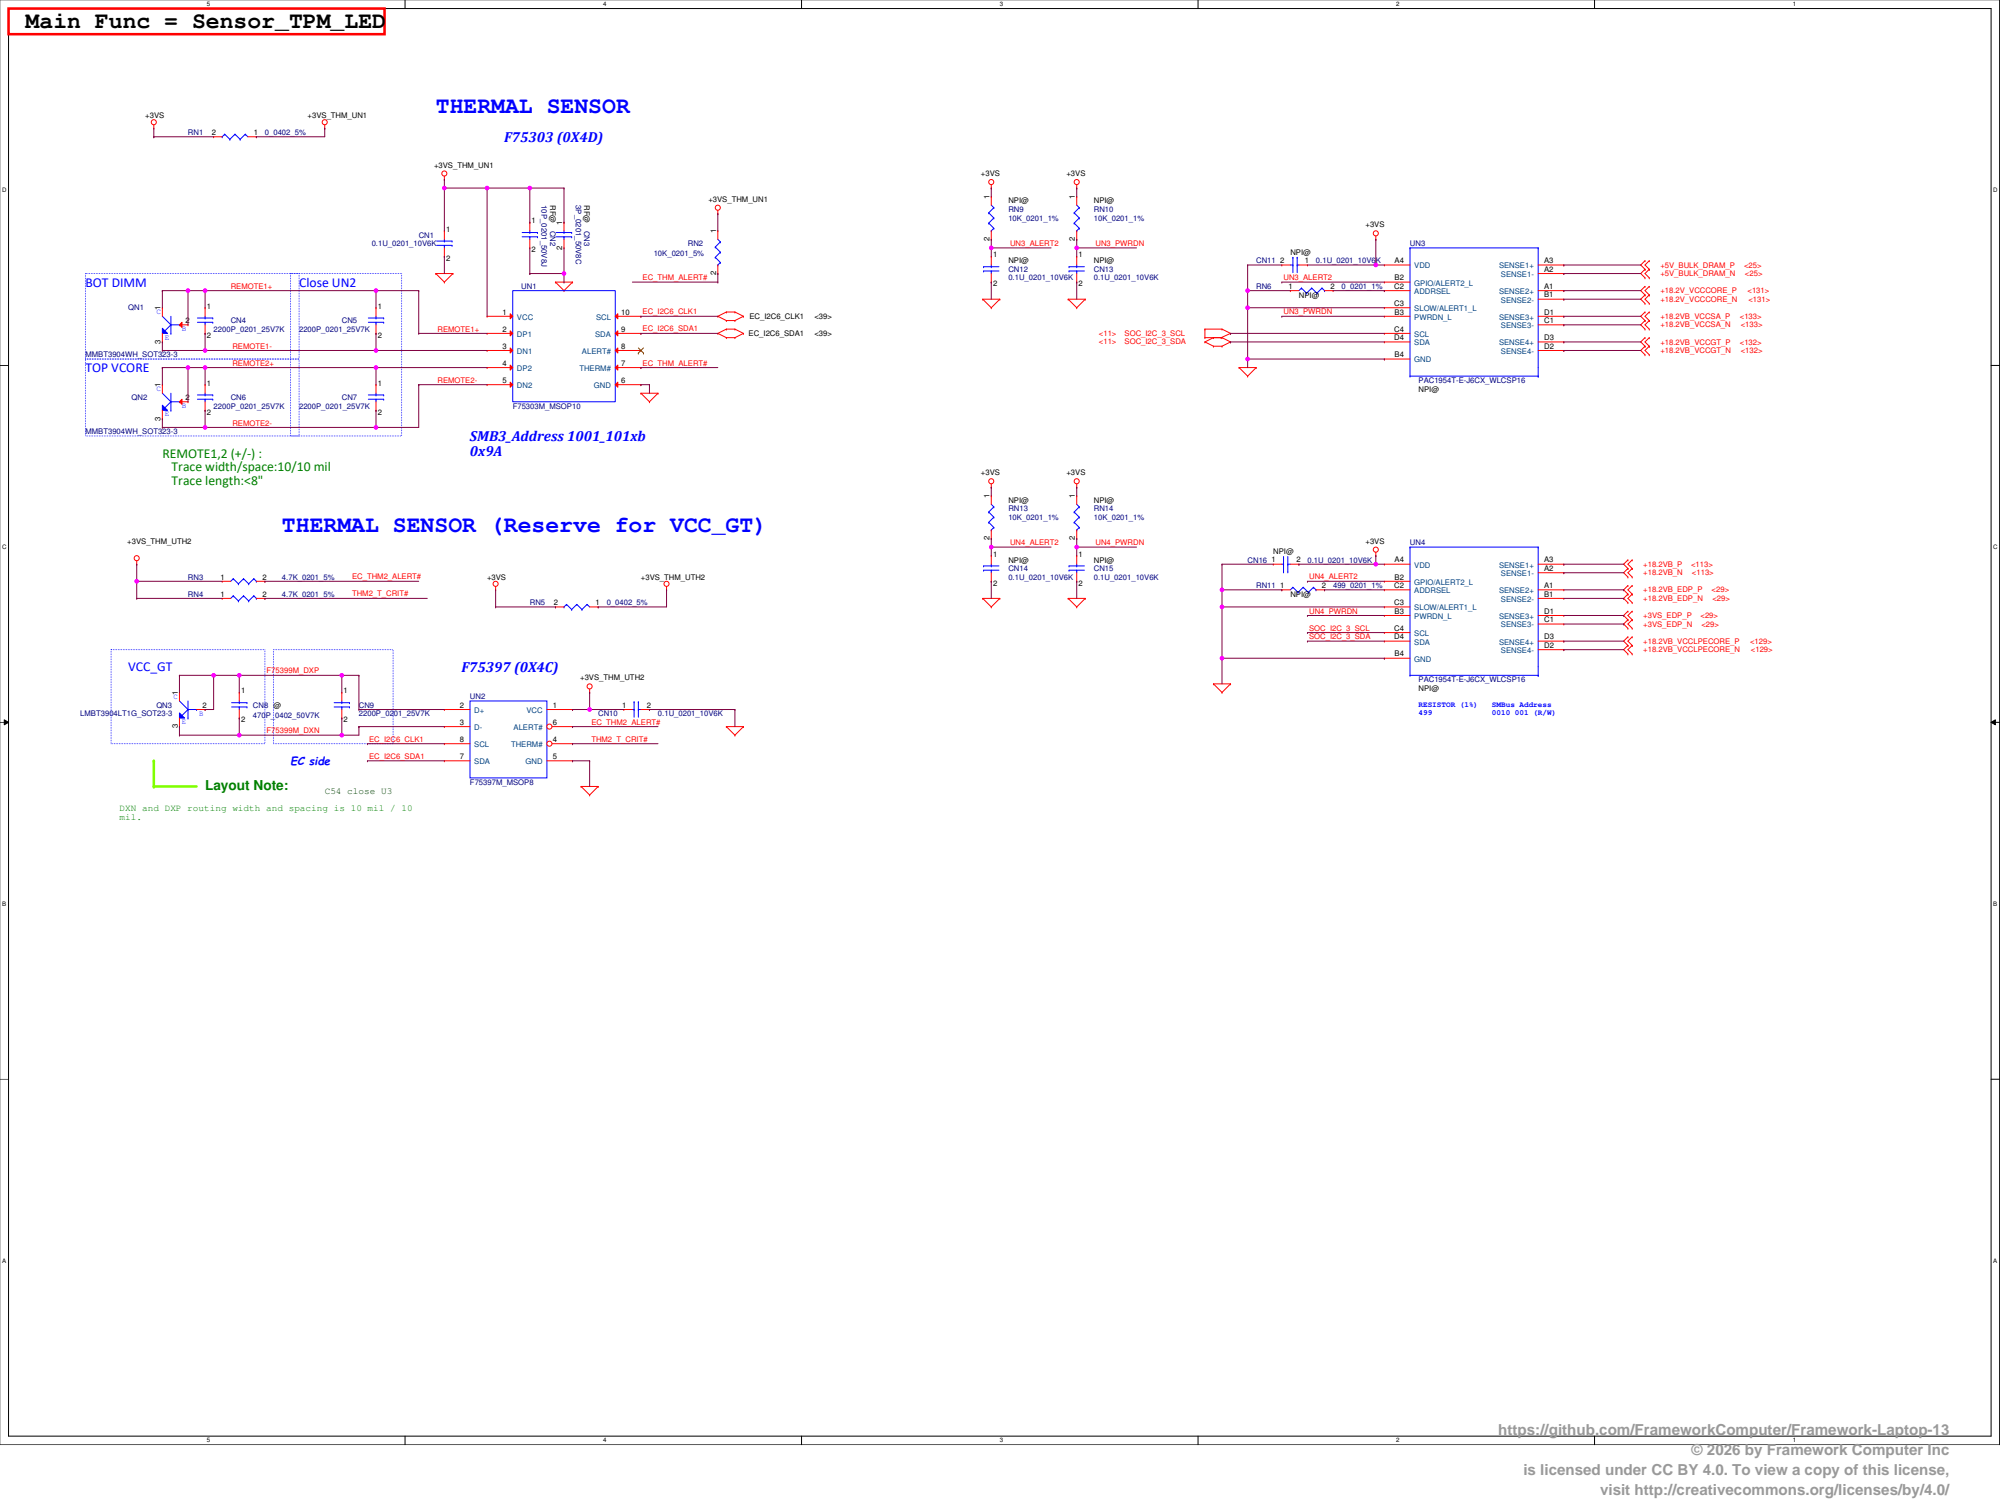
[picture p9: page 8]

REMOTE1,2 (+/-) :
Trace width/space:10/10 mil
Trace length:<8"

THERMAL SENSOR (Reserve for VCC_GT)

DXN and DXP routing width and spacing is 10 mil / 10
mil.

# ON / OFF switch

# Power Button

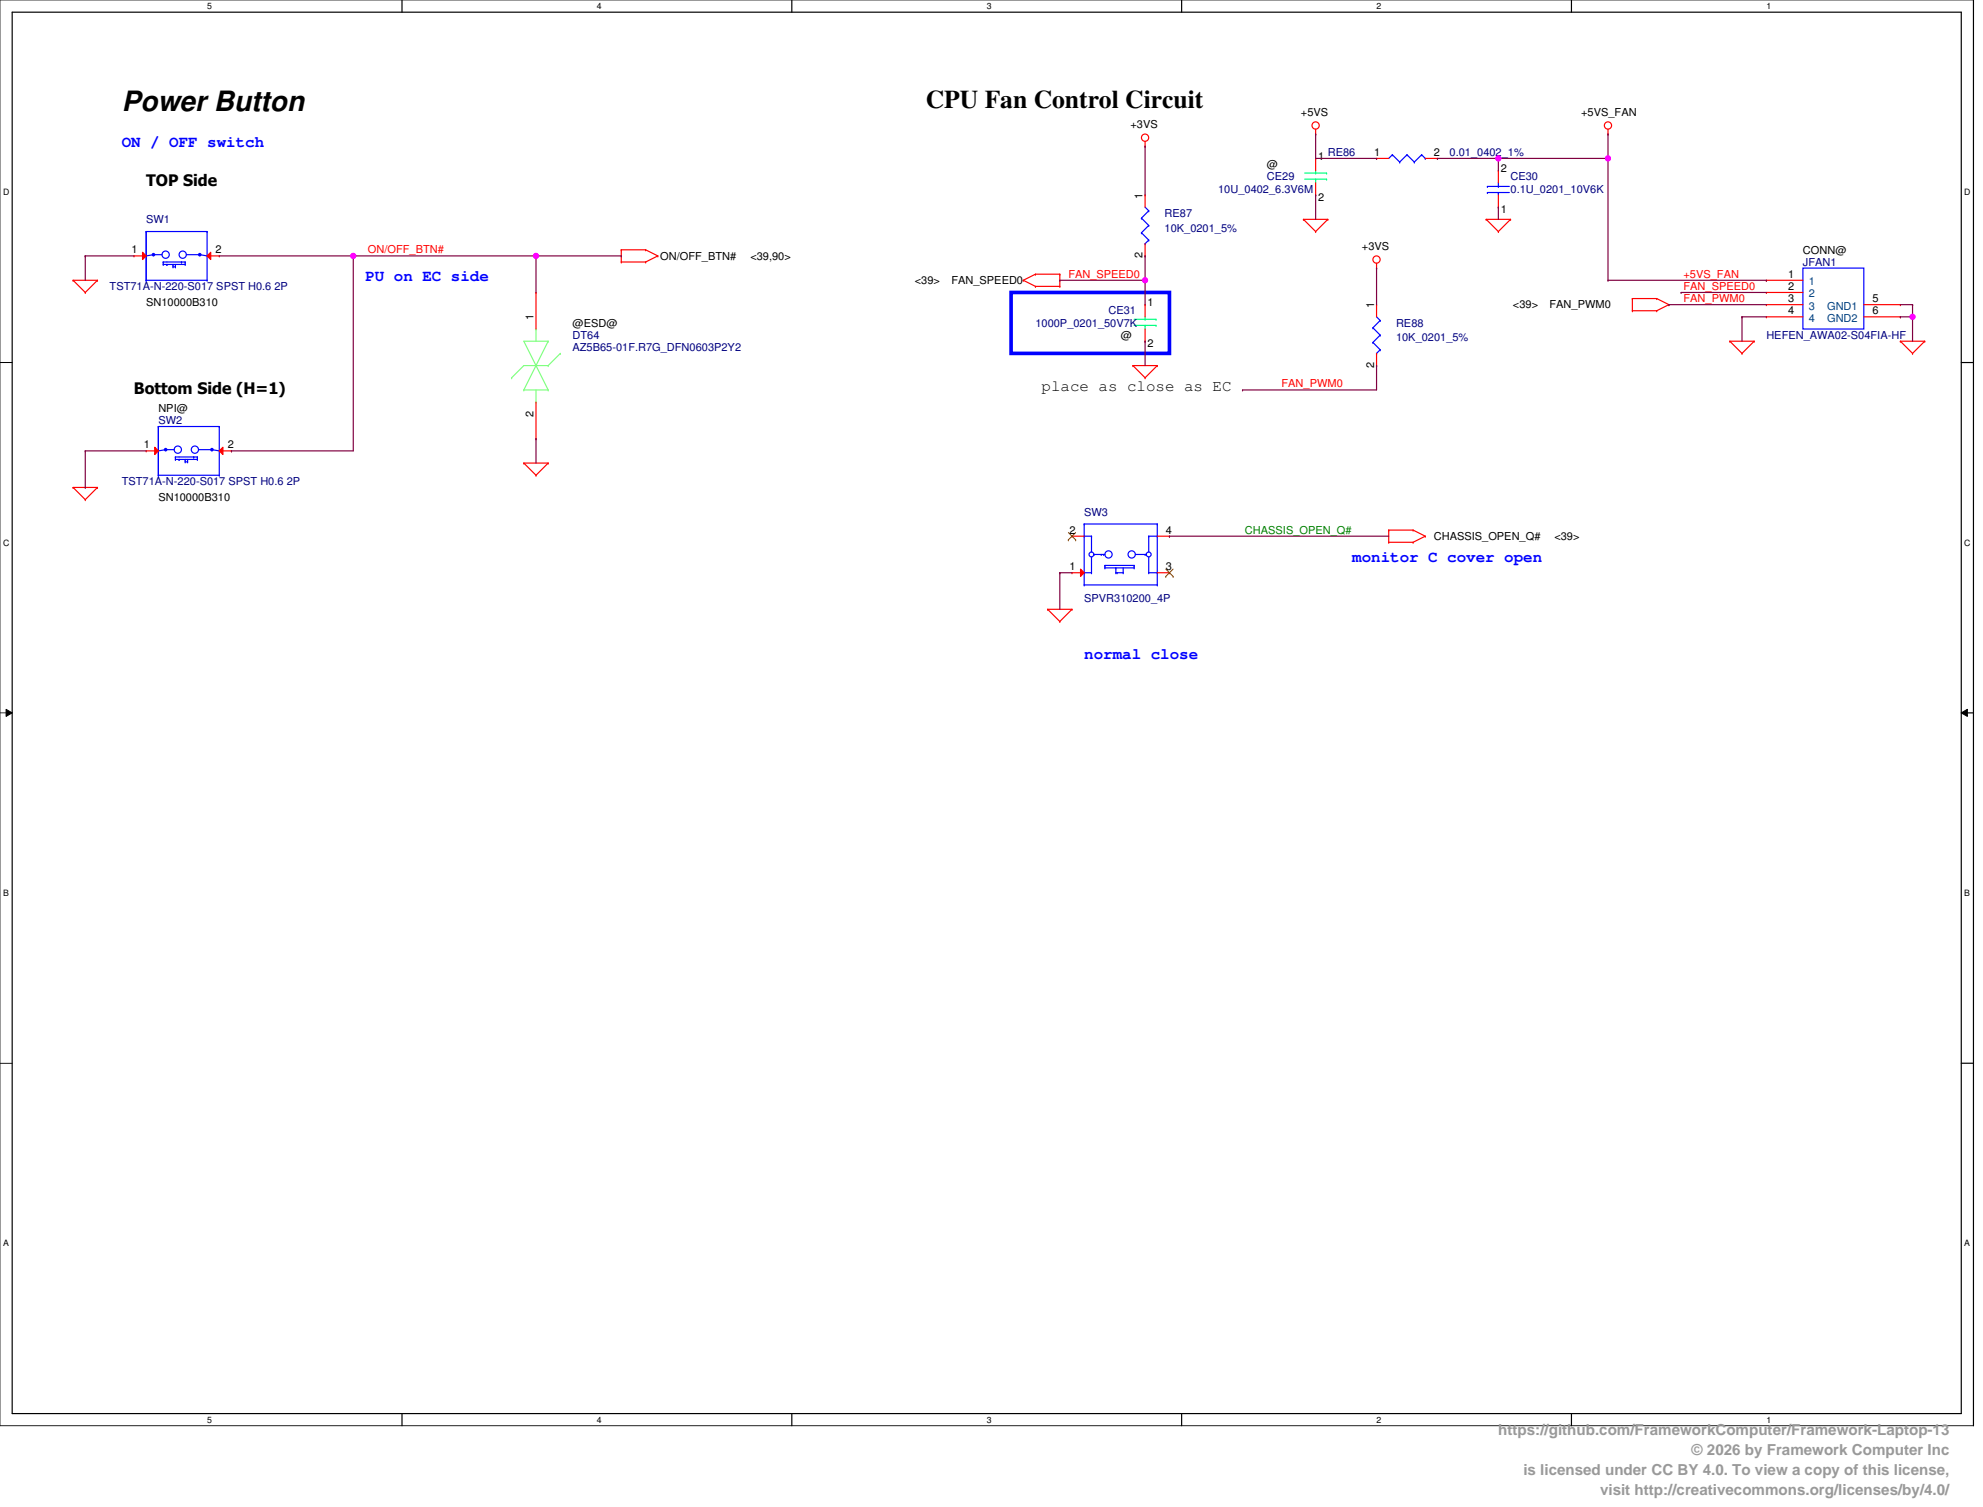
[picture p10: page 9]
normal close; TOP Side; Bottom Side (H=1); ON/OFF_BTN#; <39> FAN_SPEED0; <39> FAN_PWM0; CHASSIS_OPEN_Q#; +5VS_FAN; DT64 AZ5B65-01F.R7G_DFN0603P2Y2; @ESD@ ¹ 2; JFAN1; HEFEN_AWA02-S04FIA-HF; CONN@; GND1; GND2; SPVR310200_4P; TST71A-N-220-S017 SPST H0.6 2P; NPI@; FAN_SPEED0; FAN_SPEED0 FAN_PWM0; FAN_PWM0

CPU Fan Control Circuit

ON/OFF_BTN#
PU on EC side

place as close as EC

monitor C cover open

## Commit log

2026-05-03 fix: 'though' → 'through' in Fingerprint Reader README
2026-05-03 fix: 'connection' → 'connected' in Mainboard README
2026-06-14 Add Core Ultra Series 3 interface schematic
2026-07-14 Add STP file of webcam
    [FW_13_camera_module.stp]
